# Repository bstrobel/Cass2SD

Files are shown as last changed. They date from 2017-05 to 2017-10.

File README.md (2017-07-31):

# Cass2SD - Cassettes to SD Cards - Kassetten zu SD-Karten

Replacement for cassette recorder by an SD card as mass storage device of old East-German 8-bit computers

Ersatz des Kassettenrekorders als Massenspeichergerät für DDR-Computer (KC85/2, KC85/3 und KC87, Z9001) durch eine SD-Karte

_The rest of the README and the Wiki is written in German since the audience of this tool is most probably mainly German speaking._

_Die Kommentare im Quellcode sind in Englisch gehalten, da ich das aus meinem Beruf so gewöhnt bin und sonst
den Text erst im Kopf ins Deutsche übersetzen müsste. Ich weiß, das klingt ein wenig affektiert, ist aber nicht
so gemeint._

## Eigenschaften und Ziele des Projekts

- Der alte Kassettenrecorder soll komplett ersetzt werden, ohne dass Veränderungen an den Computern vorgenommen werden müssen.
- Die Benutzeroberfläche soll einfach und bequem zu handhaben sein. Es sollen aber auch alle relevanten Funktionen und Informationen
  zur Verfügung stehen.
- Getestet wurde mit meinen beiden KCs, einem Z9001 (KC85/1.10) und einem KC85/3.
- Das Projekt wurde mit in meinem Bastelfundus vorhandenen Teilen umgesetzt, als da wären:
  - 8-bit Microcontroller ATMEL ATMega328P-PU
  - LCD 1602 (2 Zeilen zu 16 Zeichen mit HD44780-kompatiblem Controller)
  - LM358 Doppel-OPV für den Eingangsverstärker/Schmitt-Trigger
  - MicroSD Card Adapter für Arduino, welcher schon die notwendigen Pegelwandler von 3,3V auf 5V enthält, aber leider keine Erkennung,
  ob eine Karte gesteckt ist.
  - MCP1702-5002 Festspannungsregler im TO-92 Gehäuse
  - ALPS Drehimpulsgeber mit Taster in der Drehachse aus der EC11 Serie
- Als IDE habe ich AtmelStudio 7 und als Compiler den mitgelieferten avr-gcc genutzt.
- Programmiert und debugt habe ich den Atmel mit einem AVR Dragon.
- Programmiersprache ist C.
- Benutzte OpenSource-Bibliotheken - _meinen allerherzlichsten Dank an die Autoren, ohne deren Arbeit mein Projekt wohl nicht möglich gewesen wäre_:
  - Für die LCD-Anzeige-Routinen habe ich [die Bibliothek von Peter Fleury](http://homepage.hispeed.ch/peterfleury/avr-software.html#libs)  verwendet.
  - Für die FAT- und SD-Karten-SPI-Schnittstelle benutze ich die [FatFs-Bibliothek von Elm Chan](http://elm-chan.org/fsw/ff/00index_e.html)
- Was nicht geht:
  - Dateiliste sortieren. Der AVR hat einfach nicht genug Hauptspeicher dafür. Die Dateien werden genau in der
    Reihenfolge angezeigt, in der sie in der FAT gespeichert sind.
  - Verzeichnisse anlegen.
  - Dateien und Verzeichnisse löschen.  

## [Cass2SD Wiki](https://github.com/bstrobel/Cass2SD/wiki)

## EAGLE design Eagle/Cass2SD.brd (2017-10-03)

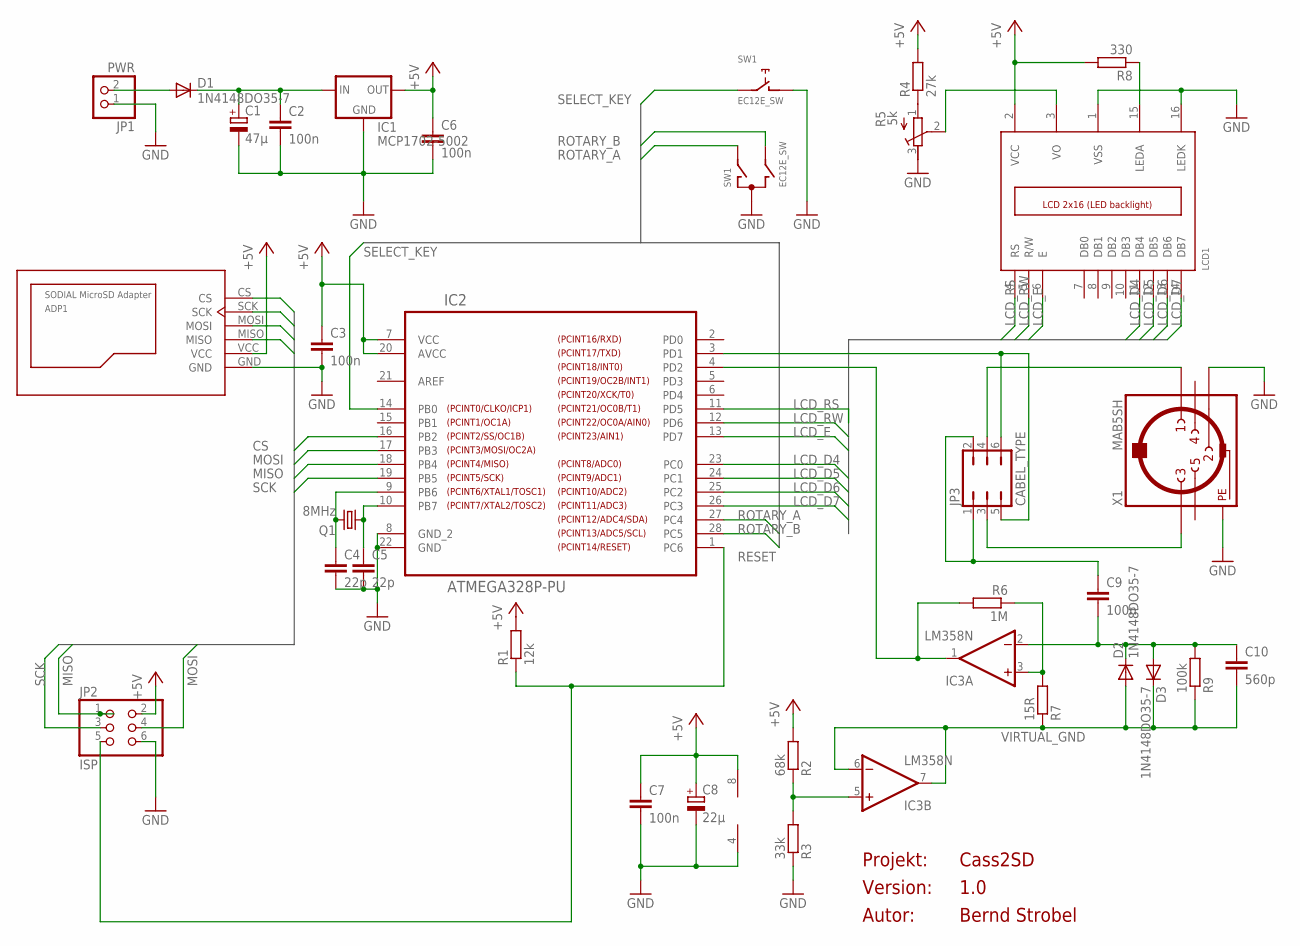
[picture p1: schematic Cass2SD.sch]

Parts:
ADP1: SODIAL_MICROSD_SPI_ADAPTER
C1: 47µ; E2,5-7
C2, C3, C6, C7, C9: 100n; C050-025X075
C4, C5: 22p; C050-025X075
C8: 22µ; E2,5-7
C10: 560p; C050-025X075
D1, D2, D3: 1N4148DO35-7; DO35-7
IC1: MCP1702-5002; TO92-
IC2: ATMEGA328P-PU; DIP254P762X457-28
IC3: LM358N; DIL08
JP1: PWR; 1X02
JP2: ISP; 2X03
JP3: CABEL_TYPE; JP3Q
LCD1: LCD_2X16; HY-1602F
Q1: 8MHz; HC49/S
R1: 12k; 0207/10
R2: 68k; 0207/10
R3: 33k; 0207/10
R4: 27k; 0207/10
R5: 5k; RTRIM64P
R6: 1M; 0207/10
R7: 15R; 0207/10
R8: 330; 0207/10
R9: 100k; 0207/10
SW1: EC12E_SW; ALPS_EC12E_SW
X1: MAB5SH

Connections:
+5V: ADP1.VCC, C3.1, C6.1, C7.1, C8.+, IC1.3 (OUT), IC2.7 (VCC), IC2.20 (AVCC), IC3.8 (V+), JP2.2, LCD1.2 (VCC), R1.2, R2.2, R4.2, R8.2
CS: ADP1.CS, IC2.16 (PB2)
GND: ADP1.GND, C1.-, C2.2, C3.2, C4.2, C5.2, C6.2, C7.2, C8.-, IC1.1 (GND), IC2.8 (GND_2), IC2.22 (GND), IC3.4 (V-), JP1.1, JP2.6, LCD1.1 (VSS), LCD1.16 (LEDK), R3.1, R5.3 (E), SW1.C, SW1.D (1), X1.2, X1.PE, X1.PE@ (PE)
LCD_D4: IC2.23 (PC0), LCD1.11 (DB4)
LCD_D5: IC2.24 (PC1), LCD1.12 (DB5)
LCD_D6: IC2.25 (PC2), LCD1.13 (DB6)
LCD_D7: IC2.26 (PC3), LCD1.14 (DB7)
LCD_E: IC2.13 (PD7), LCD1.6 (E)
LCD_RS: IC2.11 (PD5), LCD1.4 (RS)
LCD_RW: IC2.12 (PD6), LCD1.5 (R/W)
MISO: ADP1.MISO, IC2.18 (PB4), JP2.1
MOSI: ADP1.MOSI, IC2.17 (PB3), JP2.4
unnamed: C1.+, C2.1, D1.C, IC1.2 (IN)
unnamed: C9.2, C10.1, D2.C, D3.A, IC3.2 (-IN), R9.2
unnamed: IC3.5 (+IN), R2.1, R3.2
unnamed: C4.1, IC2.9 (PB6), Q1.2
unnamed: C5.1, IC2.10 (PB7), Q1.1
unnamed: C9.1, JP3.1, JP3.2
unnamed: IC3.3 (+IN), R6.1, R7.2
unnamed: IC2.4 (PD2), IC3.1 (OUT), R6.2
unnamed: D1.A, JP1.2
unnamed: IC2.3 (PD1), JP3.5, JP3.6
unnamed: LCD1.15 (LEDA), R8.1
unnamed: JP3.3, X1.3
unnamed: LCD1.3 (VO), R5.2 (S)
unnamed: R4.1, R5.1 (A)
unnamed: JP3.4, X1.1
RESET: IC2.1 (PC6), JP2.5, R1.1
ROTARY_A: IC2.27 (PC4), SW1.A
ROTARY_B: IC2.28 (PC5), SW1.B
SCK: ADP1.SCK, IC2.19 (PB5), JP2.3
SELECT_KEY: IC2.14 (PB0), SW1.E (2)
VIRTUAL_GND: C10.2, D2.A, D3.C, IC3.6 (-IN), IC3.7 (OUT), R7.1, R9.1

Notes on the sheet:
Projekt:
Version:
Autor:

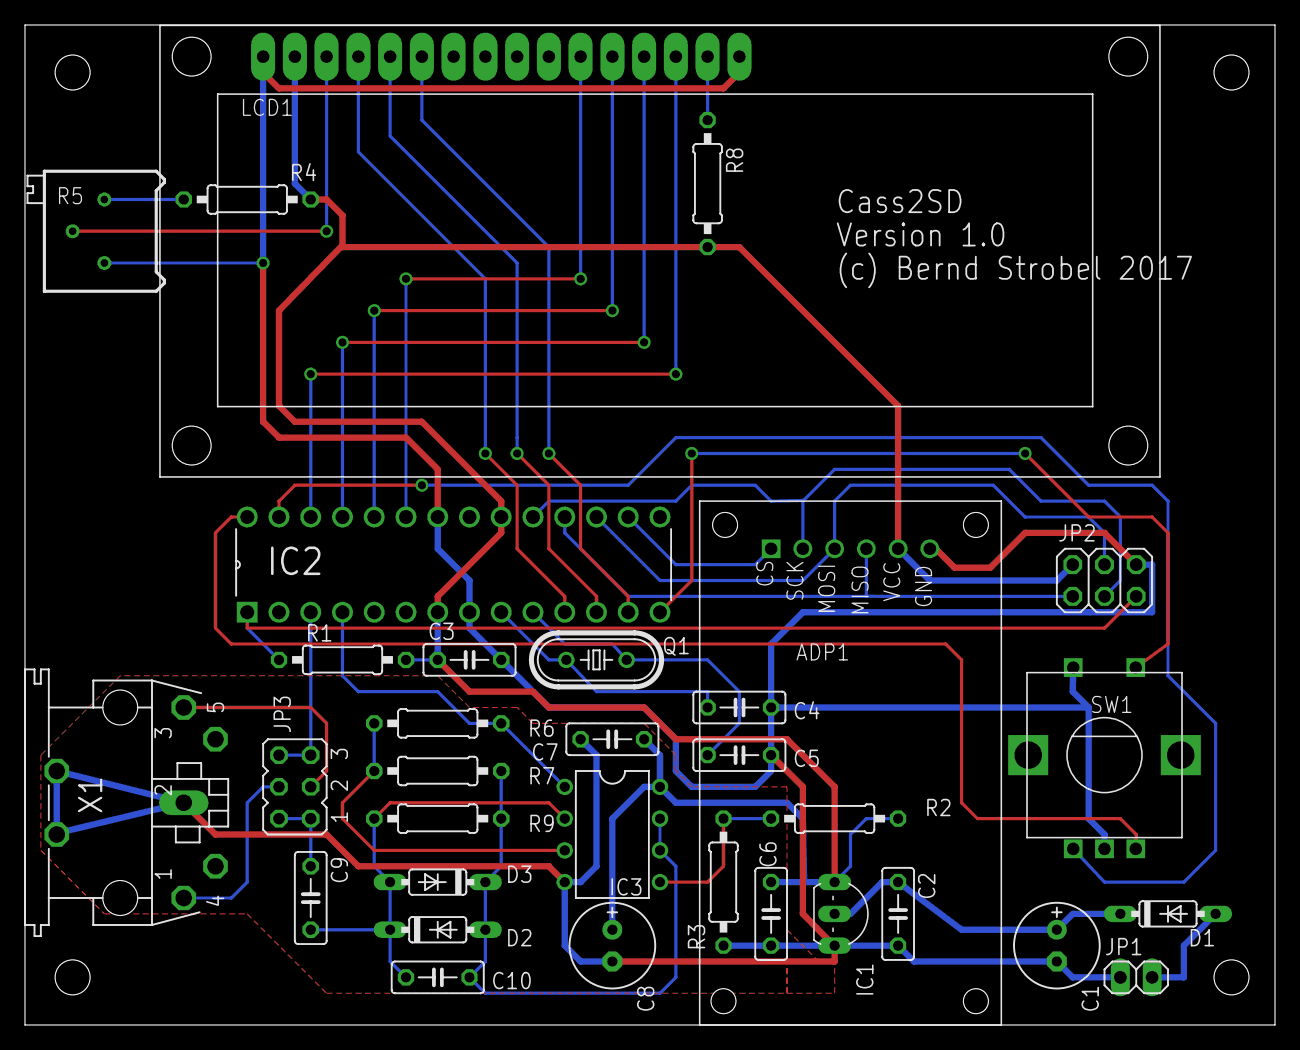
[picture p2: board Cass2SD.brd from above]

Board: 2 copper layers, 100.0 x 80.0 mm, 33 parts (0 on the bottom side), 33 nets.

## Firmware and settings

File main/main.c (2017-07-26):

/*
* main_ff_avr.c
*
* Created: 29.04.2017 12:44:25
*  Author: Bernd
*/
#include <avr/io.h>
#include <avr/interrupt.h>
#include <avr/sfr_defs.h>
#include <avr/sleep.h>
#include <avr/power.h>
#define __PROG_TYPES_COMPAT__
#include <avr/pgmspace.h>
#include <string.h>
#include <util/delay.h>
#include <stdbool.h>
#include "../ff_avr/xitoa.h"
#include "../ff_avr/ff.h"
#include "../ff_avr/diskio.h"
#include "../lcd/lcd.h"
#include "debounced_keys.h"
#include "display_util.h"
#include "kc_cass_send_file.h"
#include "kc_cass_recv_file.h"
#include "kc_cass_common.h"

/************************************************************************/
/* To be called at the very beginning                                   */
/************************************************************************/
static void power_save_config()
{
	// ports are configured as input by default.
	// this enables the pullups.
	PORTB = 0xFF;
	PORTC = 0xFF;
	PORTD = 0xFF;
	power_twi_disable();
	power_adc_disable();
	power_usart0_disable();
	set_sleep_mode(SLEEP_MODE_IDLE);
	sleep_bod_disable();
	sleep_enable();
}

int main(void)
{
	// do the init stuff
	power_save_config();
	lcd_init(LCD_DISP_ON);
	xdev_out(lcd_putc);
	keys_init();
	sei();
	disk_and_debounce_timer_init();

	lcd_clrscr();
	xprintf(PSTR("INITIALIZING"));
	lcd_gotoxy(0,1);
	xprintf(PSTR("SD CARD"));
	// mount the SD card
	{
		char chars[4] = {'-','+','|','#'};
		uint8_t i = 0;
		do
		{
			fr = f_mount(&FatFs, "", 1);
			if (fr != FR_OK)
			{
				if (fr == FR_NOT_READY) {
					lcd_gotoxy(15,1);
					lcd_putc(chars[i++]);
					if (i > 3) {
						i=0;
					}
				}
				else {
					disp_fr_err(fr);
				
				}
			}
		}
		while (fr != FR_OK);
	}
	
	kc_cass_send_file_init();
	kc_cass_recv_file_init();
	
	// initialize the menu system and display greeting
	f_opendir(&Dir,"/");
	disp_util_fill_dir_name();
	dir_idx = -1;
	display_next();
	
	select_key_changed = false;
	// main loop
	while(1)
	{
		kc_cass_handle_recv_file();
		if (system_state != IDLE) {
			continue; // we dont want to sleep while we receive or send a file
		}
		switch(display_task)
		{
		case UP:
			display_prev();
			display_task=STAY;
			break;
		case DOWN:
			display_next();
			display_task=STAY;
			break;
		case STAY:
			break;
		}
		if (select_key_changed && select_key_pressed)
		{
			select_key_changed = false;
			switch (dir_idx)
			{
				case DIR_IDX_GO_UP:
				{
					disp_util_fill_dir_name();
					f_chdir("..");
					f_opendir(&Dir,".");
					display_by_name(dir_name, true);
					disp_util_fill_dir_name();
					break;
				}
				default:
				{
					if (Finfo.fattrib & AM_DIR)
					{
						f_chdir(Finfo.fname);
						disp_util_fill_dir_name();
						f_opendir(&Dir,".");
						dir_idx = -1;
						display_next();
					}
					else
					{
						if (Finfo.fname[0])
						{
							send_file(&Finfo);
						}
					}
					break;
				}
			}
			is_file_details_displayed = false;
		}
		disp_timer++;
		if (disp_timer > DISP_FILE_DETAILS_TIMEOUT_COUNT && !is_file_details_displayed && system_state == IDLE) {
			display_file_details();
		}
		// sleep until an interrupt wakes us up
		// (disk_and_debounce_timer does this ~4000 times a second)
		sleep_cpu();
	}
	
}

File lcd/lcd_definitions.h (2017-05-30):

/*
 * lcd_definitions.h
 *
 * Created: 4/24/2017 8:34:36 AM
 *  Author: Bernd
 */ 

 // This file will only be used if the symbol _LCD_DEFINITIONS_FILE is defined (i.e. -D_LCD_DEFINITIONS_FILE)!

#ifndef LCD_DEFINITIONS_H_
#define LCD_DEFINITIONS_H_

#define LCD_PORT         PORTC        /**< port for the LCD lines   */
#define LCD_DATA0_PORT   LCD_PORT     /**< port for 4bit data bit 0 */
#define LCD_DATA1_PORT   LCD_PORT     /**< port for 4bit data bit 1 */
#define LCD_DATA2_PORT   LCD_PORT     /**< port for 4bit data bit 2 */
#define LCD_DATA3_PORT   LCD_PORT     /**< port for 4bit data bit 3 */
#define LCD_DATA0_PIN    0            /**< pin for 4bit data bit 0  */
#define LCD_DATA1_PIN    1            /**< pin for 4bit data bit 1  */
#define LCD_DATA2_PIN    2            /**< pin for 4bit data bit 2  */
#define LCD_DATA3_PIN    3            /**< pin for 4bit data bit 3  */
#define LCD_RS_PORT      PORTD        /**< port for RS line         */
#define LCD_RS_PIN       5            /**< pin 11 for RS line         */
#define LCD_RW_PORT      PORTD        /**< port for RW line         */
#define LCD_RW_PIN       6            /**< pin 12 for RW line         */
#define LCD_E_PORT       PORTD        /**< port for Enable line     */
#define LCD_E_PIN        7            /**< pin 13 for Enable line     */

#endif /* LCD_DEFINITIONS_H_ */

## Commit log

2017-06-05 Refactoring, filetype handling, BASIC files not working
    [kc_cass_interface.h, main.c]
2017-06-25 Refactoring, Interrupt send
2017-06-25 Interrupt Send bug fixed
2017-06-25 VORTON based on current_block
2017-06-25 Initial implementation of receive code - NOT TESTED!
    ...so most probably not working yet.
    [kc_cass_recv_file.h, main.c]
2017-07-08 LTSpice Simulation of input circuit
2017-07-08 Many changes, recording not working yet
    [kc_cass_recv_file.h, main.c]
2017-07-08 LTSpice Simu input stage as schmitt trigger
2017-07-08 Input stage now with correct schmitt trigger
2017-07-09 File name detection during recieve not working yet
    [kc_cass_recv_file.h, main.c]
2017-07-18 File receive works, SD Card SPI problem, Timer2 bug fixed
    [debounced_keys.h, kc_cass_recv_file.h, main.c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]
2017-07-26 Saving files on KC85/3 fixed (long spaces), key debouncer optimized
    [Cass2SD.sch]
2017-07-27 Circuit schematics of cassette interfaces added
2017-07-27 Geracord circuit
2017-07-28 Timer1 init bug fixed, FCB generation for RAW fixed
2017-08-07 Eagle files updated/added
    [Cass2SD.brd, Cass2SD.sch]
2017-10-03 Changed to external XTAL with 16MHz
    [Cass2SD.brd, Cass2SD.sch]
